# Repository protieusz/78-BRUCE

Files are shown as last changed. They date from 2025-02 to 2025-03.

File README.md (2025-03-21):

# 78-BRUCE
Condensed version of the Batarang with interchangeable 25mm or 34mm trackball powered with integrated RP2040 and hot swaps

# Sponsorship
Thank you PCBWay for sponsoring my 78-BRUCE. For all your custom PCB/PCBA service you can count on PCBWay.  Top notch quality and awesome customer service. Their customer service will notify you if there are commponents that they are unable to get and will ask you if their suggested alternative component is good. Customer service will keep track of your progress and notify you.
PCBWay

# Featured
https://kbd.news/78-BRUCE-2617.html 

# Disclaimer
This work is a non-commercial fan creation of custom keyboard case and PCB in the shape of a bat from the Batman series. It is made out of love and respect for the Batman series. All rights to Batman and related content are owned by Warner Bros. Entertainment Inc. and its associated companies. The images, names, storylines and other elements of Batman used in this work are the property of their respective copyright holders. Unauthorized commercial use is strictly prohibited. The license of this design reflects not for commercial use.
Please print and use the case and PCB at your own risk.

# Description
A condensed version from my previous Batarang/Armored Batarang versions https://github.com/protieusz/Batarang-Armored-Version. 34 keys column staggered with either a 34mm or 25mm interchangeable trackball in the middle. PCB is powered by integrated RP2040. For diodes I use the BAV70, 1 pair of common cathodes 1.25V@150mA 200mA SOT-23 Switching Diodes.  Trackball sensor is the good old PMW3360. This time for the trackball holder, I decided to go back and use ma_po_daisuki's https://ma-po.booth.pm/items/5258743 intechangeable designs. Please support him by buying his STEP files. Case STL files will be uploaded ~~soon~~ to MakerWorld https://makerworld.com/en/models/1207063-78-bruce#profileId-1221103. Please BOOST me whenever you can so I can be motivated to create more stuff. Thanks. QMK code as always copy pasted from bally's of aki27. No support will be given. Please print this design at your own risk.

# Full Production Pictures
Mar 16, 2025





















# Preview
FE8FFA852EA59D5F60CBFC2532B9CC85
CE873F901C951DBF9FAC3A0B1C04C74C
C3468EDBADA2574E4ECD7B01223AAD4F
A37BE0411C5BF1ADE1337224B73DCF95
A8C676B6467891B2E3953B19715B3780
8B7DB3F6AC7652F58BC3FA37173D43A6

Screenshot 2025-02-21 at 10 16 29 AM
Screenshot 2025-02-25 at 10 51 32 AM
Screenshot 2025-02-25 at 10 51 49 AM
Screenshot 2025-02-20 at 9 17 04 AM
Screenshot 2025-02-19 at 7 46 14 AM
Screenshot 2025-02-18 at 6 02 32 AM

# License

</a></p>

You are free to:

Share — copy and redistribute the material in any medium or format

Adapt — remix, transform, and build upon the material

The licensor cannot revoke these freedoms as long as you follow the license terms.
Under the following terms:

Attribution — You must give appropriate credit, provide a link to the license, and indicate if changes were made. You may do so in any reasonable manner, but not in any way that suggests the licensor endorses you or your use.

NonCommercial — You may not use the material for commercial purposes.

ShareAlike — If you remix, transform, or build upon the material, you must distribute your contributions under the same license as the original.

No additional restrictions — You may not apply legal terms or technological measures that legally restrict others from doing anything the license permits.

78-BRUCE by ProtieusKeebs is licensed under [CC BY-NC-SA 4.0](https://creativecommons.org/licenses/by-nc-sa/4.0/?ref=chooser-v1)

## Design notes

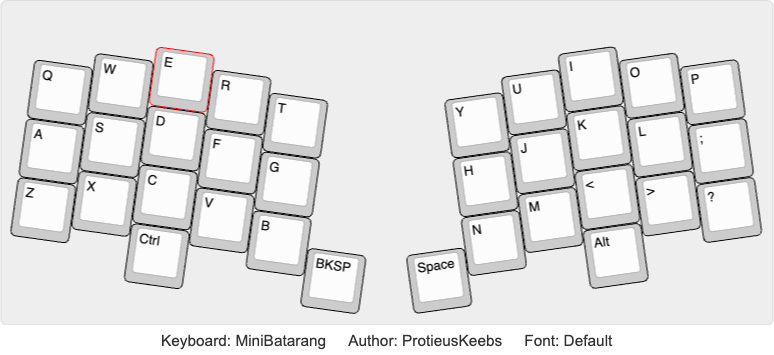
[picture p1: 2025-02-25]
keyboard-layout.png

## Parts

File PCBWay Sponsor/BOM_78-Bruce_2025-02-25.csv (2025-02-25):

ID | Name | Designator | Footprint | Quantity | Manufacturer Part | Manufacturer | Supplier | Supplier Part | Price | link
1 | 1uF | C1,C2,C5,C6,C9 | C0402 | 5 | CL05A105KA5NQNC | SAMSUNG(三星) | LCSC | C52923 | 0.003 | https://item.szlcsc.com/15869.html
2 | 22pF | C3,C4 | C0402 | 2 | 0402CG220J500NT | FH(风华) | LCSC | C1555 | 0.001 | https://item.szlcsc.com/15869.html
3 | 100nF | C7,C10,C11,C12,C13,C14,C15,C16 | C0402 | 8 | CL05B104KO5NNNC | SAMSUNG(三星) | LCSC | C1525 | 0.001 | https://item.szlcsc.com/15869.html
4 | 10uF | C8 | C0402 | 1 | CL05A106MQ5NUNC | SAMSUNG(三星) | LCSC | C15525 | 0.004 | https://item.szlcsc.com/15869.html
5 | 4.7uF | C17,C19,C20 | C0402 | 3 | CL05A475MP5NRNC | SAMSUNG(三星) | LCSC | C23733 | 0.005 | https://lcsc.com/eda_search?q=C23733&%26type=1&ref=editor
6 | 100nF | C18 | C0402 | 1 | CL05B104KB54PNC | SAMSUNG(三星) | LCSC | C307331 | 0.005 | https://lcsc.com/eda_search?q=C307331&%26type=1&ref=editor
7 | BAV70-C68978 | D000,D002,D004,D006,D008,D100,D102,D104,D106,D108,D200,D202,D204,D206,D208,D302,D305 | SOT-23-3_L3.0-W1.7-P0.95-LS2.9-BR | 17 | BAV70 | CJ(江苏长电/长晶) | LCSC | C68978 | 0.017 | https://item.szlcsc.com/139341.html
8 | PRTR5V0U2X,215 | D11 | SOT-143_L2.9-W1.3-P1.92-LS2.3-BR | 1 | PRTR5V0U2X,215 | Nexperia(安世) | LCSC | C12333 | 0.094 | https://item.szlcsc.com/280548.html
9 | nSMD050 | F1 | F1206 | 1 | nSMD050 | 台湾陆海 | LCSC | C69688 | 0.04 | https://atta.szlcsc.com/upload/public/pdf/source/20200518/C553934_4CFF0660EAE88BF7A646763F248900C5.pdf
10 | 5.1kΩ | R1,R2,R3,R4,R5 | R0402 | 5 | 0402WGF5101TCE | UNI-ROYAL(厚声) | LCSC | C25905 | 0.001 | https://item.szlcsc.com/323315.html
11 | 1kΩ | R6,R7 | R0402 | 2 | 0402WGF1001TCE | UNI-ROYAL(厚声) | LCSC | C11702 | 0.001 | https://item.szlcsc.com/323315.html
12 | 27Ω | R8,R9 | R0402 | 2 | 0402WGF270JTCE | UNI-ROYAL(厚声) | LCSC | C25100 | 0.001 | https://item.szlcsc.com/323315.html
13 | 10kΩ | R10,R12,R13 | R0402 | 3 | 0402WGF1002TCE | UNI-ROYAL(厚声) | LCSC | C25744 | 0.001 | https://lcsc.com/eda_search?q=C25744&%26type=1&ref=editor
14 | 39Ω | R11 | R0402 | 1 | 0402WGJ0390TCE | UNI-ROYAL(厚声) | LCSC | C25164 |  | https://lcsc.com/eda_search?q=C25164&%26type=1&ref=editor
15 | 15kΩ | R14 | R0402 | 1 | 0402WGF1502TCE | UNI-ROYAL(厚声) | LCSC | C25756 | 0.001 | https://lcsc.com/eda_search?q=C25756&%26type=1&ref=editor
16 | RESET | U1 | RESET SWITCH | 1 |  |  |  |  |  |  | [DNP不要贴];
17 | BOOT | U2 | RESET SWITCH | 1 |  |  |  |  |  |  | [DNP不要贴];
18 | W25Q128JVSIQTR | U3 | SOIC-8_L5.3-W5.3-P1.27-LS8.0-BL | 1 | W25Q128JVSIQ | WINBOND(华邦) | LCSC | C97521 | 0.514 | https://item.szlcsc.com/63461.html
19 | RP2040 | U4 | LQFN-56_L7.0-W7.0-P0.4-EP | 1 | RP2040 | Raspberry Pi(树莓派) | LCSC | C2040 | 1.032 | https://atta.szlcsc.com/upload/public/pdf/source/20210621/C2040_96F425825606B7957D87DD32E2512CA9.pdf
20 | XC6206P332MR | U5 | SOT-23-3_L2.9-W1.6-P1.90-LS2.8-BR | 1 | XC6206P332MR | TOREX(特瑞仕) | LCSC | C5446 | 0.095 | https://item.szlcsc.com/14454.html
21 | AP2127K-ADJTRG1 | U10 | SOT-23-5_L3.0-W1.7-P0.95-LS2.8-BR | 1 | AP2127K-ADJTRG1 | DIODES(美台) | LCSC | C96343 | 0.075 | https://lcsc.com/eda_search?q=C96343&%26type=1&ref=editor
22 | PMW3360DM-T2QU | U11 | PMW3360DM-T2QU.PACK | 1 | PMW3360DM-T2QU |  |  |  |  | http://www.pixart.com/upload/PMS0058-PMW3360DM-T2QU-NNDS-R1.30-06042016_20160902201411.pdf | [DNP不要贴];
23 | TYPE-C-31-M-12 | USBC1 | USB-C_SMD-TYPE-C-31-M-12 | 1 | TYPE-C-31-M-12 | 韩国韩荣 | LCSC | C165948 | 0.175 | https://so.szlcsc.com/global.html?c=&k=C165948
24 | 12MHz | X1 | OSC-SMD_4P-L3.2-W2.5-BL | 1 | X322512MSB4SI | YXC(扬兴晶振) | LCSC | C9002 | 0.068 | https://item.szlcsc.com/15866.html
25 | Kailh MX Hotswap | K000,K001,K002,K003,K004,K005,K006,K007,K008,K009,K100,K101,K102,K103,K104,K105,K106,K107,K108,K109,K200,K201,K202,K203,K204,K205,K206,K207,K208,K209,K302,K304,K305,K307 | KAILH MX HOTSWAP | 34 | 4958 | Adafruit Industries LLC | Digi-Key | 1528-4958-ND |  | https://www.digikey.fr/fr/products/detail/adafruit-industries-llc/4958/13997772 | [DNP不要贴];

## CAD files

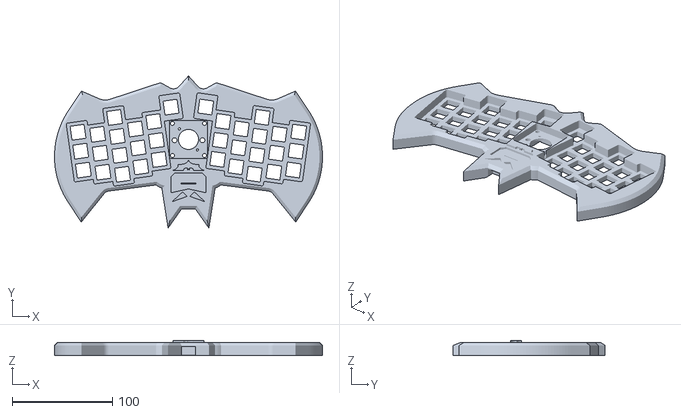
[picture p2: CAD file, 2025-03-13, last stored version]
MiniBatarangTop.stl
267.1 x 151.8 x 15.0

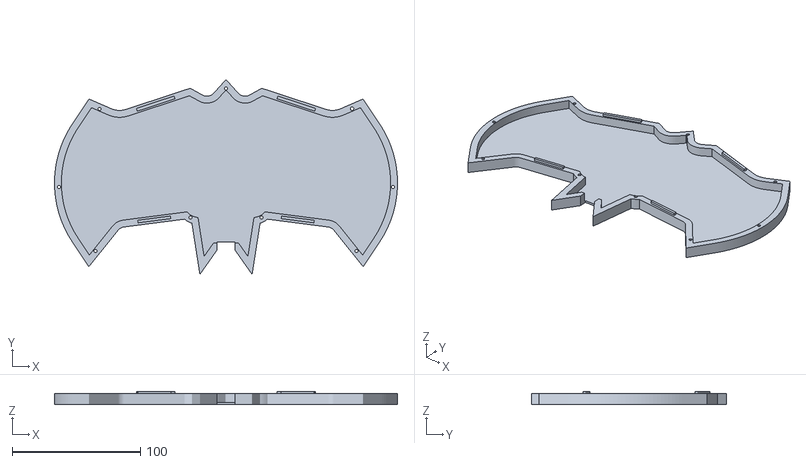
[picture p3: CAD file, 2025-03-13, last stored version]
MiniBatarangBottom.stl
267.1 x 151.8 x 10.4

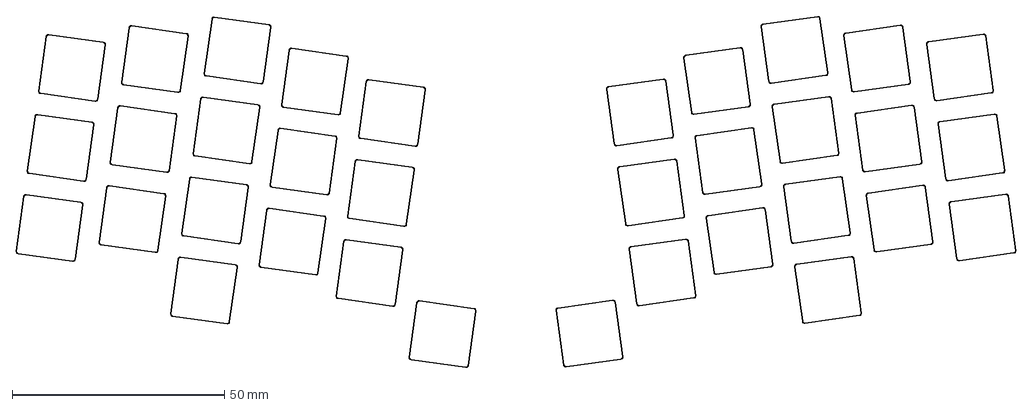
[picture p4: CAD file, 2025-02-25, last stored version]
minibswitchplate1.25.dxf
235.7 x 82.8 mm

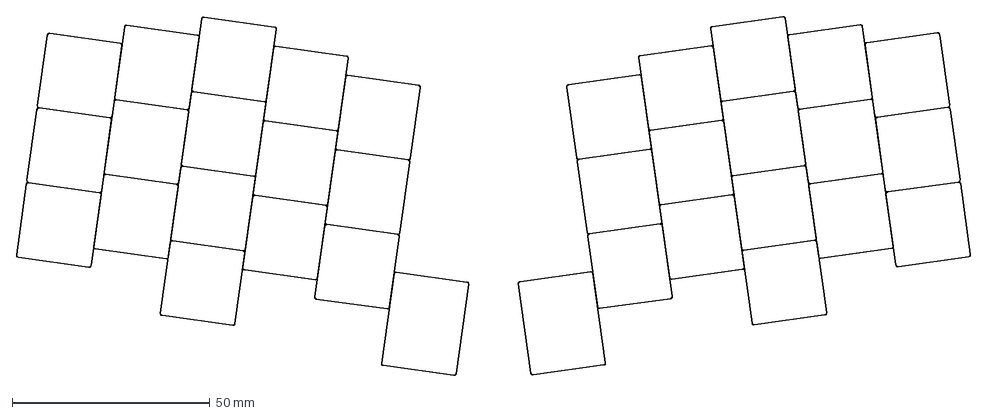
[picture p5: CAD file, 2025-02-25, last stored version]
minibkeycap1.25.dxf
241.4 x 90.8 mm

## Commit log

2025-02-25 BOM & placement files
    [BOM_78-Bruce_2025-02-25.csv, PickAndPlace_PCB_78-Bruce_2025-02-25.csv]
2025-02-25 Keylayout dxf
    [minibkeycap1.25.dxf, minibswitchplate1.25.dxf]
2025-03-13 Case files
    [MiniBatarangBottom.stl, MiniBatarangTop.stl]
2025-03-14 Sponsored Gerbers, BOM, component placement
    [BOM_78-Bruce_2025-02-25.csv, PickAndPlace_PCB_78-Bruce_2025-02-25.csv]

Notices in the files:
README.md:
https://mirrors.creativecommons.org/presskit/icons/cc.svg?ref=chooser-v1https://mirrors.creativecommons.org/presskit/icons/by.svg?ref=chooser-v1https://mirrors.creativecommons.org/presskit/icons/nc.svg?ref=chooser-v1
